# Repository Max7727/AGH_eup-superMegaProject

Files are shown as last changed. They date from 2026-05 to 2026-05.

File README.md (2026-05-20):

# AGH_eup-superMegaProject in Altium

### Schematics
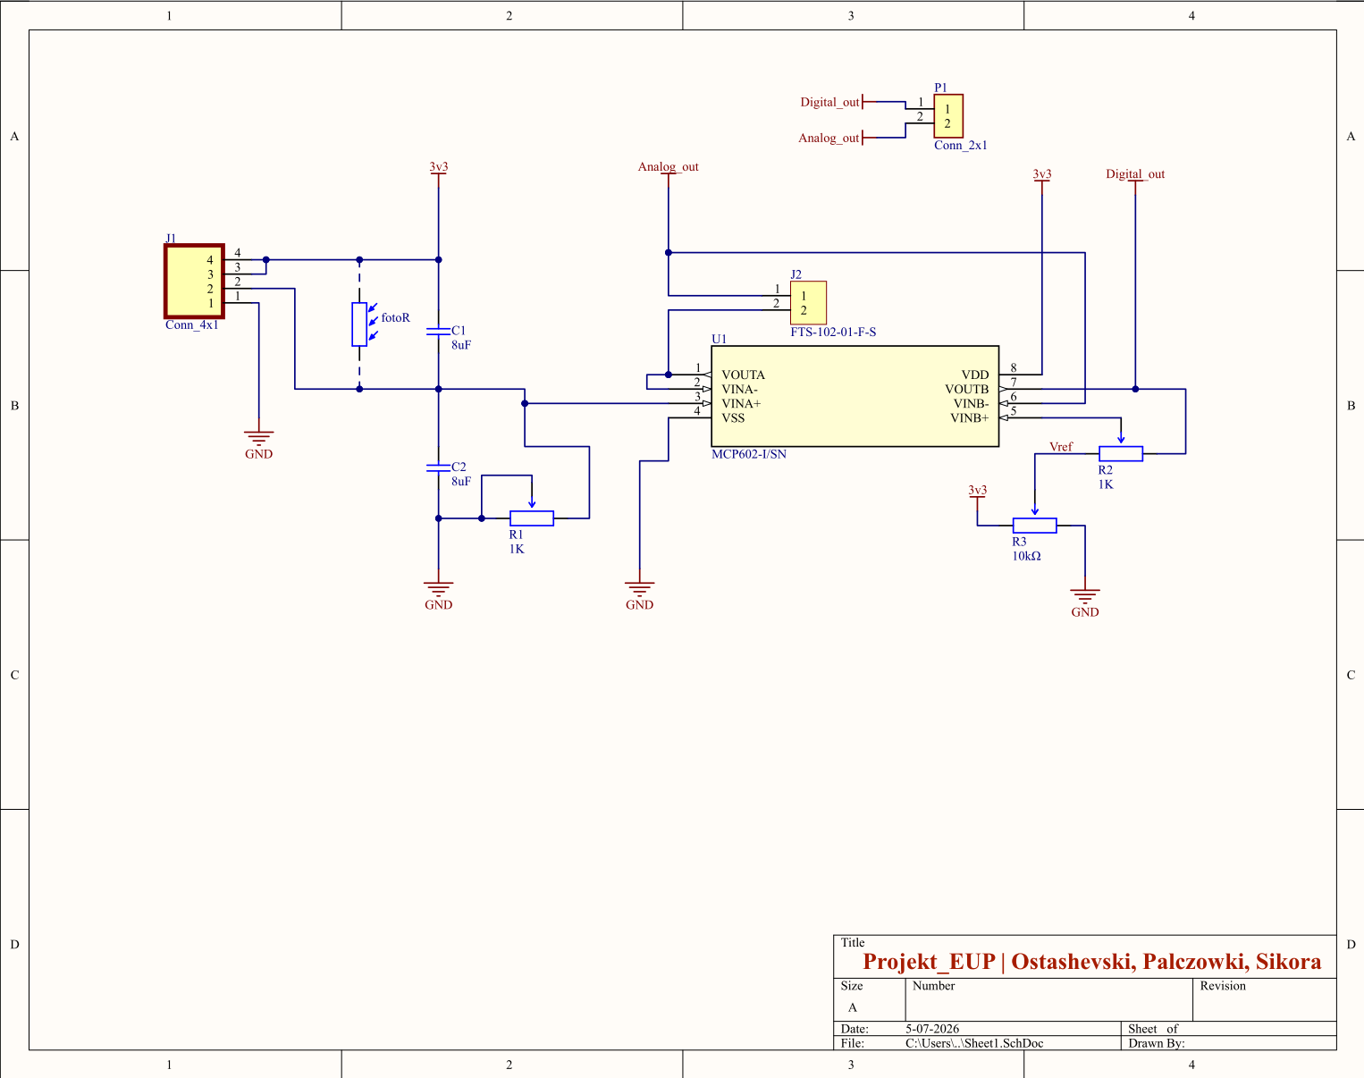
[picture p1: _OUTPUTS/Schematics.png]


### Prototype
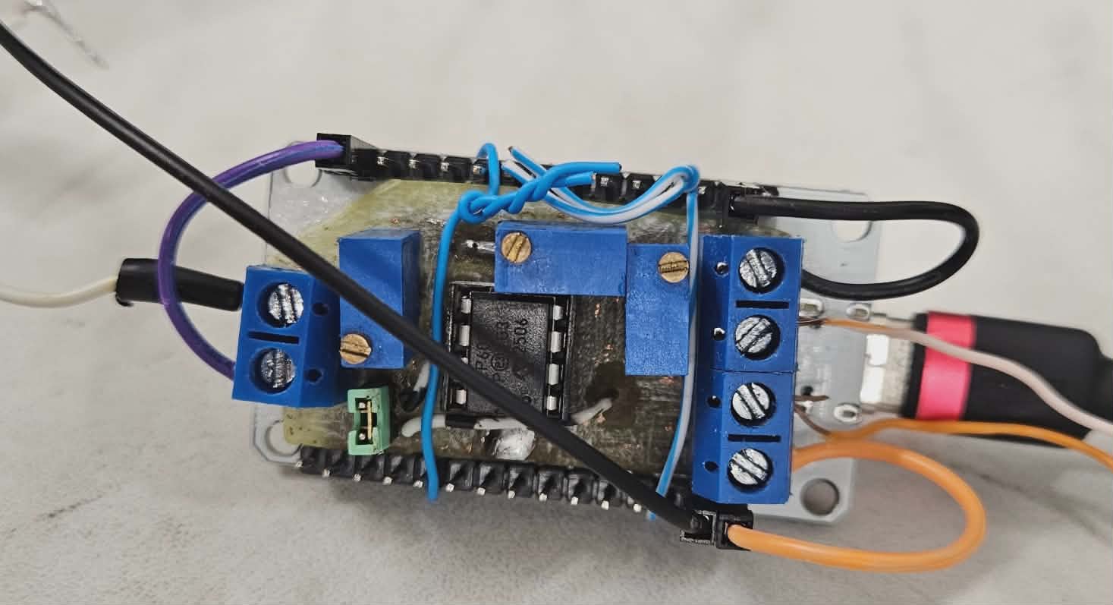
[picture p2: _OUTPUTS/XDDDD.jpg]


###  SuperMegaPCB_v1

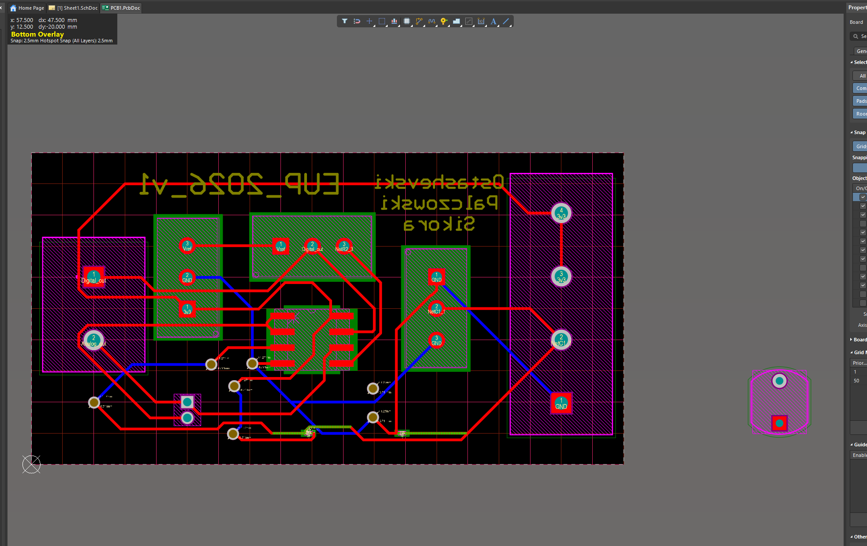
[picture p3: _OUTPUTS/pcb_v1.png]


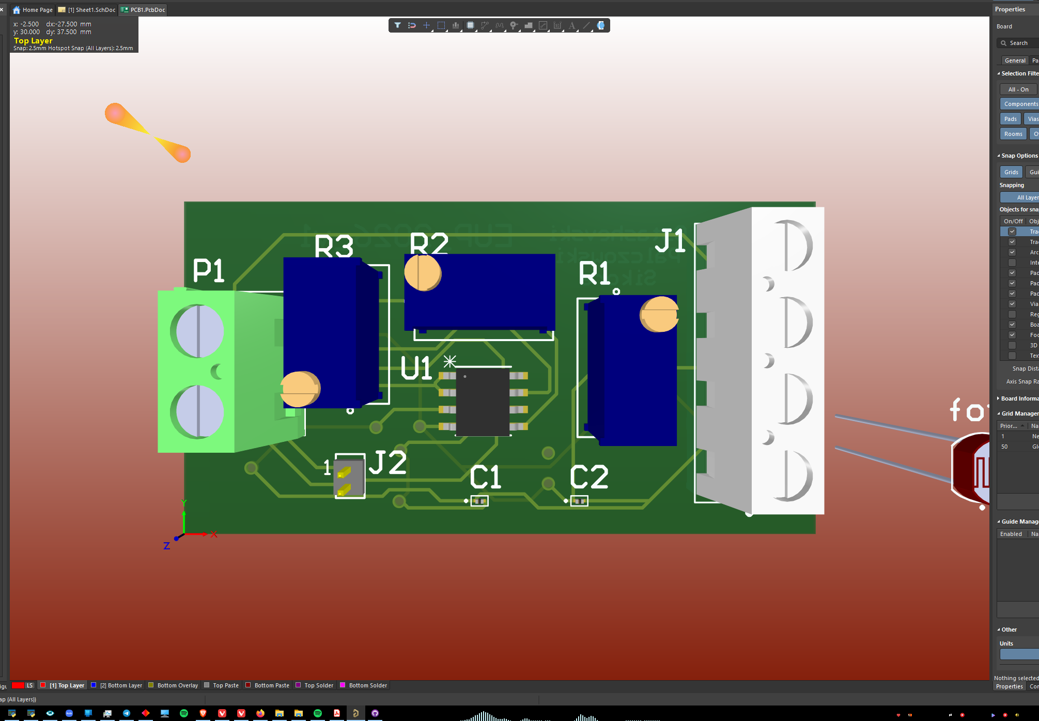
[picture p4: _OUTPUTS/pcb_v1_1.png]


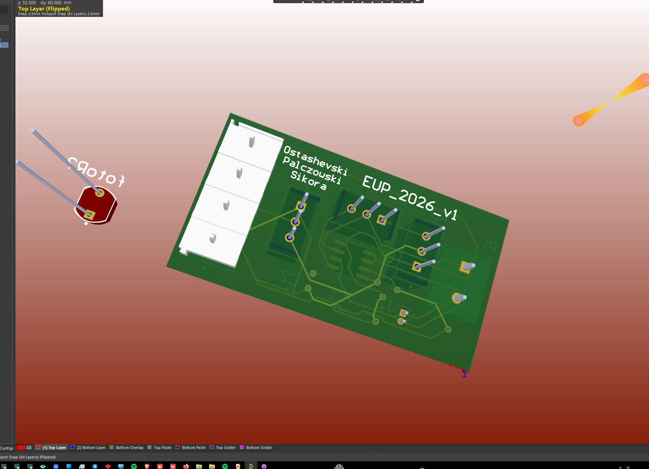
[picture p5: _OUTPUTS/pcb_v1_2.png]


###  SuperMegaPCB_v2
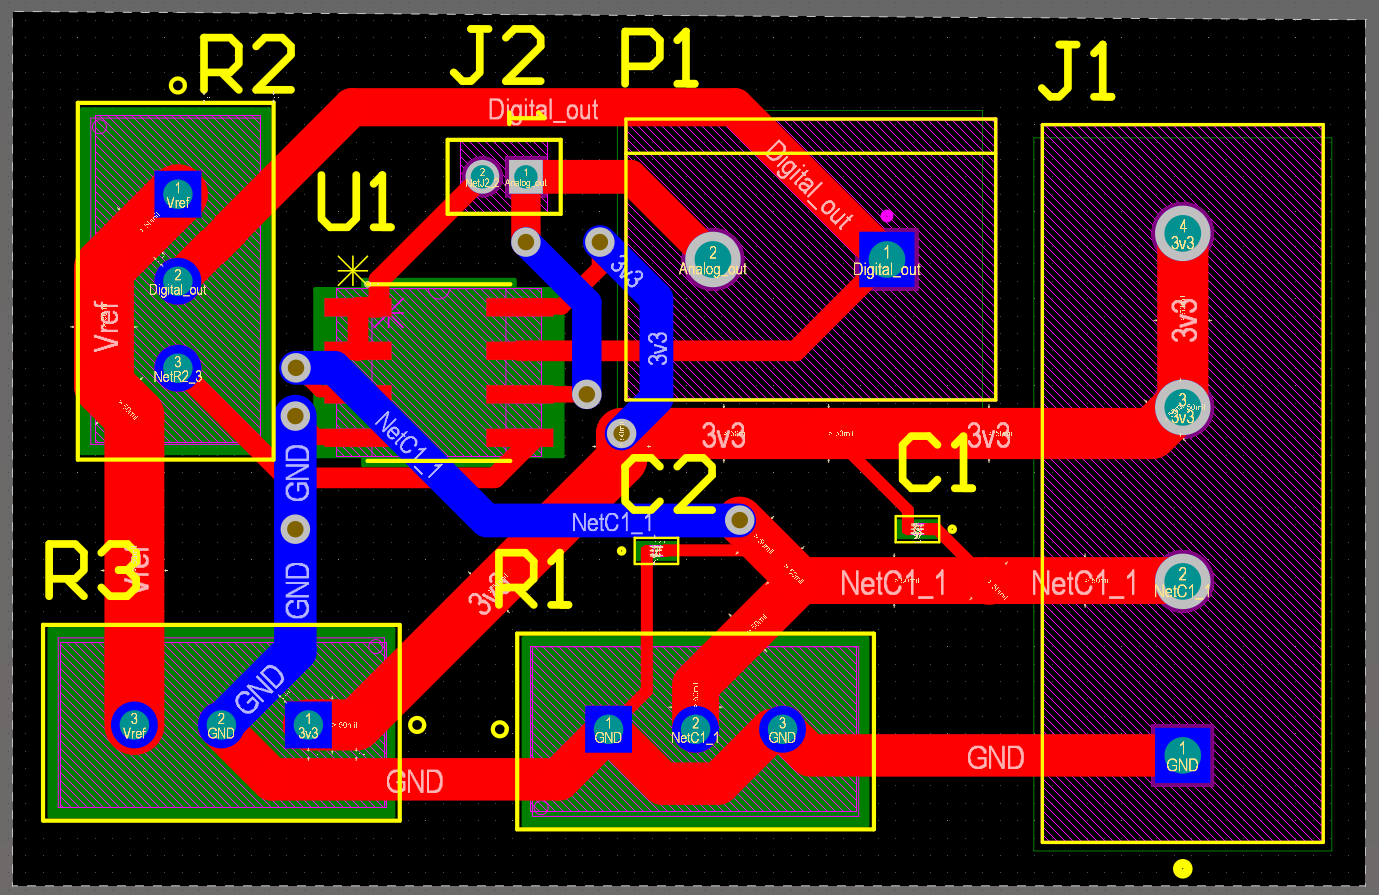
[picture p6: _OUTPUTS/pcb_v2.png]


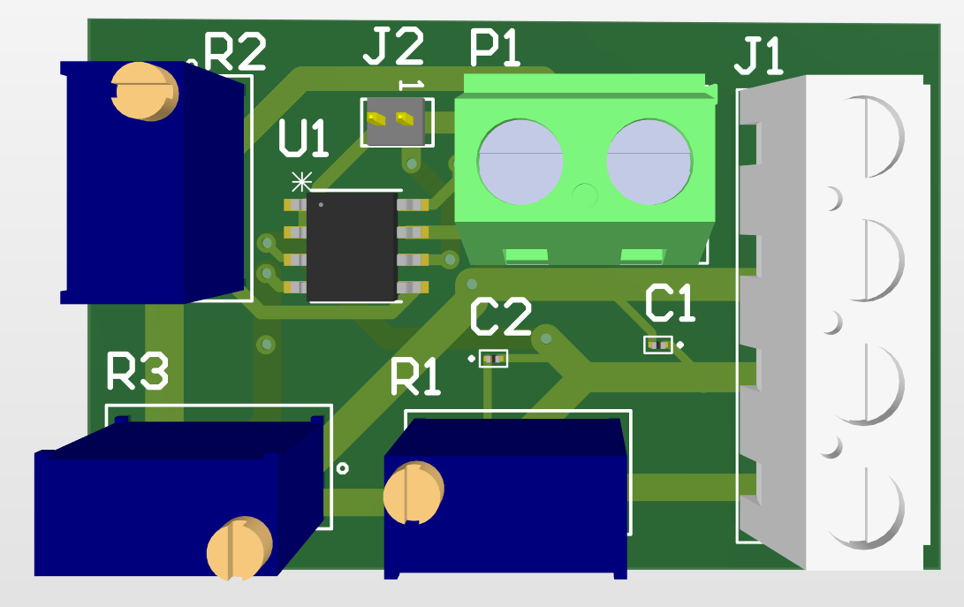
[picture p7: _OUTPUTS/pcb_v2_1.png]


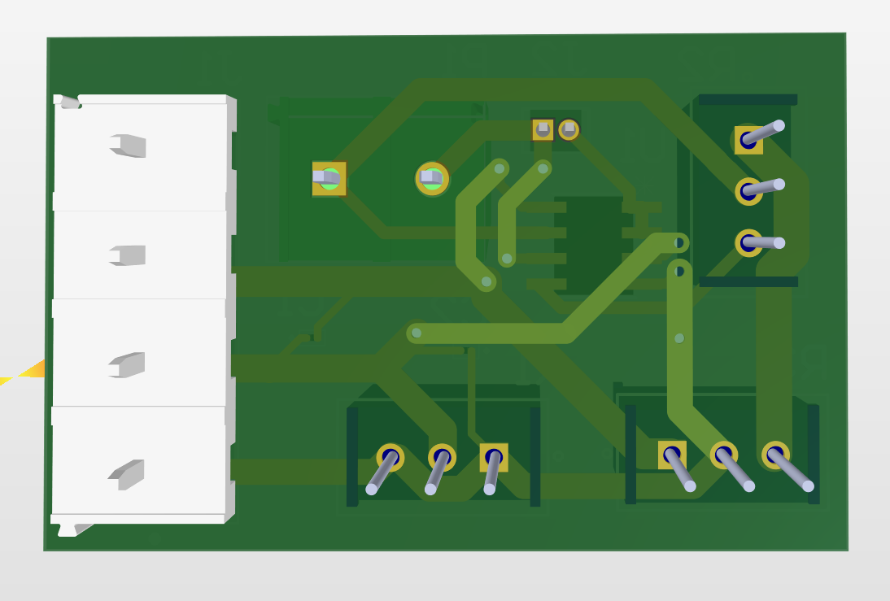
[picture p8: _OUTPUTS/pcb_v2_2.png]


### Special thanks to
Maksymilain Osyaszewski

Konrad Palczowski

Dawid Sikoea

### - - - 

Upload - 20May2026

Altium 25.8.1

:))))))

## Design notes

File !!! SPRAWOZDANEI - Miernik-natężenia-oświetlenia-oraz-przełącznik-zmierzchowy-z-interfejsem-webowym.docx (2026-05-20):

# Miernik natężenia oświetlenia oraz przełącznik zmierzchowy z interfejsem webowym (ESP32)

# 1. Wstęp

Projekt obejmował stworzenie hybrydowego (analogowo-cyfrowego) systemu monitorowania natężenia światła. Rozwiązanie łączy klasyczną elektronikę analogową (kondycjonowanie sygnału, sprzętowa histereza) z nowoczesnymi technologiami sieciowymi (ESP32, WebServer). Głównym celem było uzyskanie stabilnego pomiaru w luksach oraz realizacja przełącznika zmierzchowego.

# 2. Projekt układu analogowego i dobór elementów

### 2.1. Koncepcja wejścia: Dzielnik napięcia zamiast mostka

Początkowe założenia obejmowały wykorzystanie mostka Wheatstone'a. Po analizie zrezygnowaliśmy z tego rozwiązania. Nieliniowość mostka, nałożona na logarytmiczną i silnie nieliniową charakterystykę fotorezystorów, uniemożliwiłaby wyznaczenie prostego modelu matematycznego do obliczania luksów. Zastosowano dzielnik napięcia złożony z fotorezystora ( R_f ) oraz potencjometru wieloobrotowego.

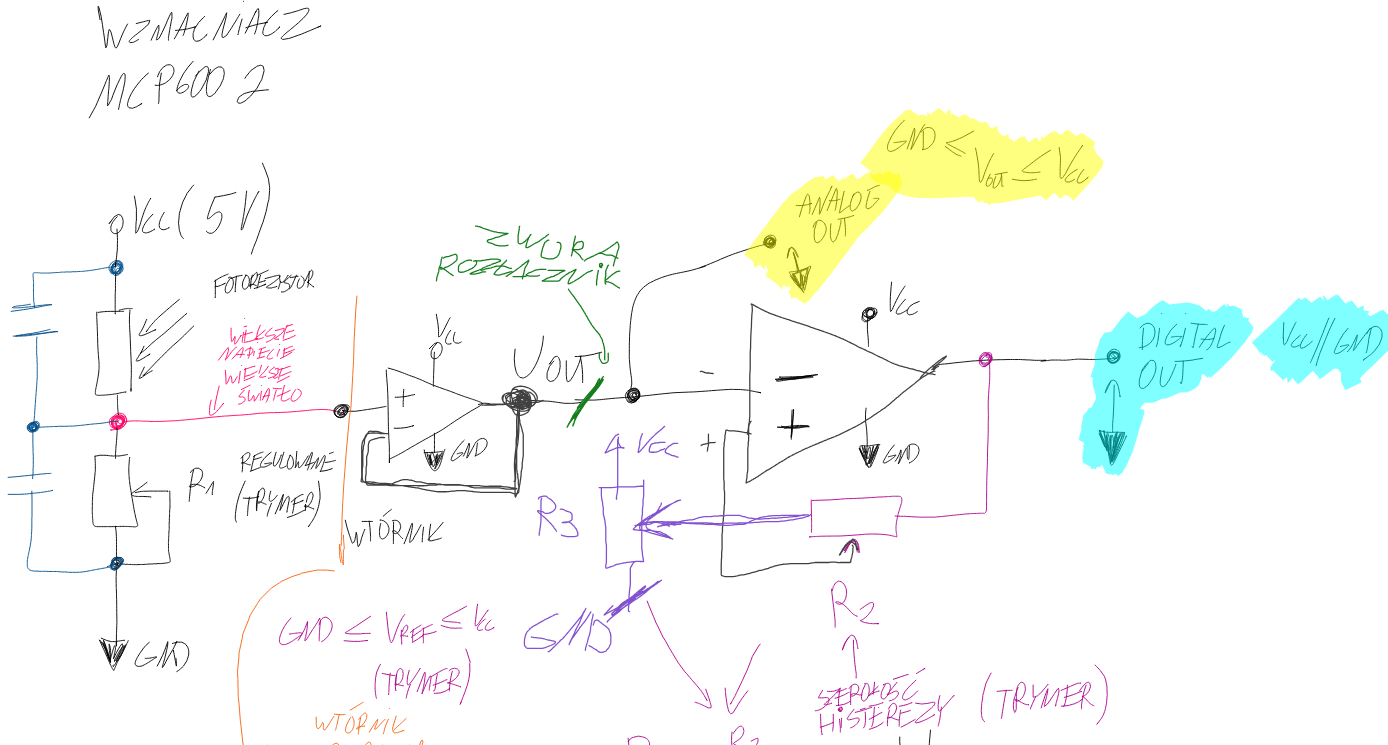
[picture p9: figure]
Brak opisu.

Rys. 1. Odręczny schemat ideowy układu przedstawiający koncepcję dzielnika, wtórnika i komparatora.

### 2.2. Dobór wzmacniacza operacyjnego

Ze względu na zasilanie układu napięciem 3.3V z modułu ESP32, zastosowanie standardowych wzmacniaczy (np. LM358) powodowałoby obcinanie sygnału wyjściowego. Zastosowano układ z wyjściem typu Rail-to-Rail (MCP602/MCP6002), co gwarantuje pełny zakres dynamiki sygnału.

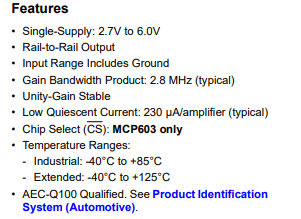
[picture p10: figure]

Rys. 2. Fragment noty katalogowej MCP6002 potwierdzający właściwości wyjścia Rail-to-Rail oraz zakres napięć roboczych.

### 2.3. Schemat ideowy

Sygnał z dzielnika podlega filtracji dolnoprzepustowej (kondensatory C_1 ,C_2 ) w celu eliminacji szumów, a następnie trafia na wtórnik napięciowy. Zapewnia to separację impedancyjną między czujnikiem a resztą układu.

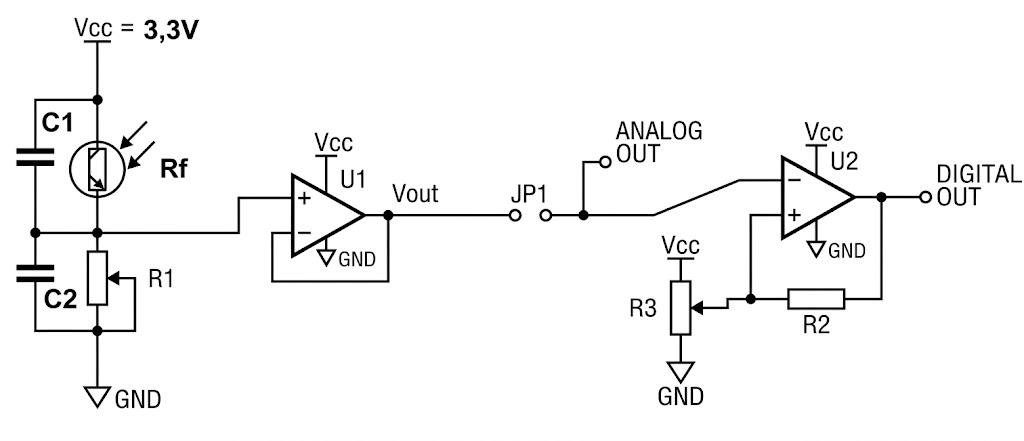
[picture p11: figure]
Brak opisu.

Rys. 3. Docelowy schemat układu analogowego wraz z podziałem na część pomiarową (wtórnik) i przełączającą (komparator).

# 3. Komparator i sprzętowa pętla histerezy

Druga część układu analogowego to komparator w konfiguracji odwracającej (spadek oświetlenia załącza wyjście). Aby zapobiec niestabilności i migotaniu sygnału na granicy przełączenia, zaimplementowano sprzętową histerezę poprzez dodatnie sprzężenie zwrotne.

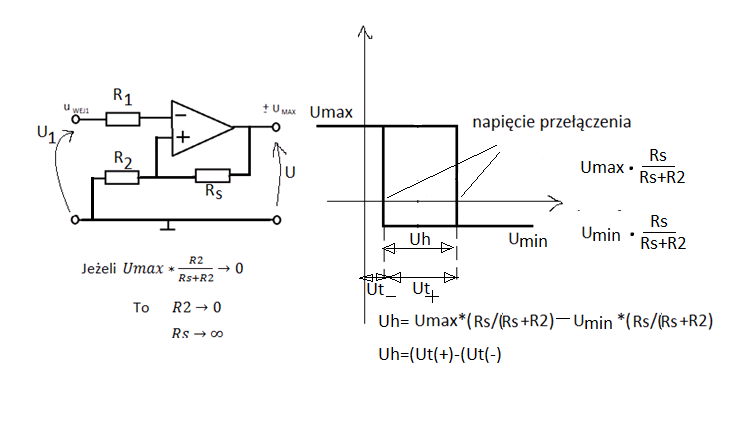
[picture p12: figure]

Rys. 4. Teoretyczny model pętli histerezy wraz z wyprowadzeniem wzorów na progi przełączania (U_max, U_min).

# 4. Symulacja komputerowa układu

Przed montażem fizycznym układ poddano symulacji w oprogramowaniu typu SPICE.

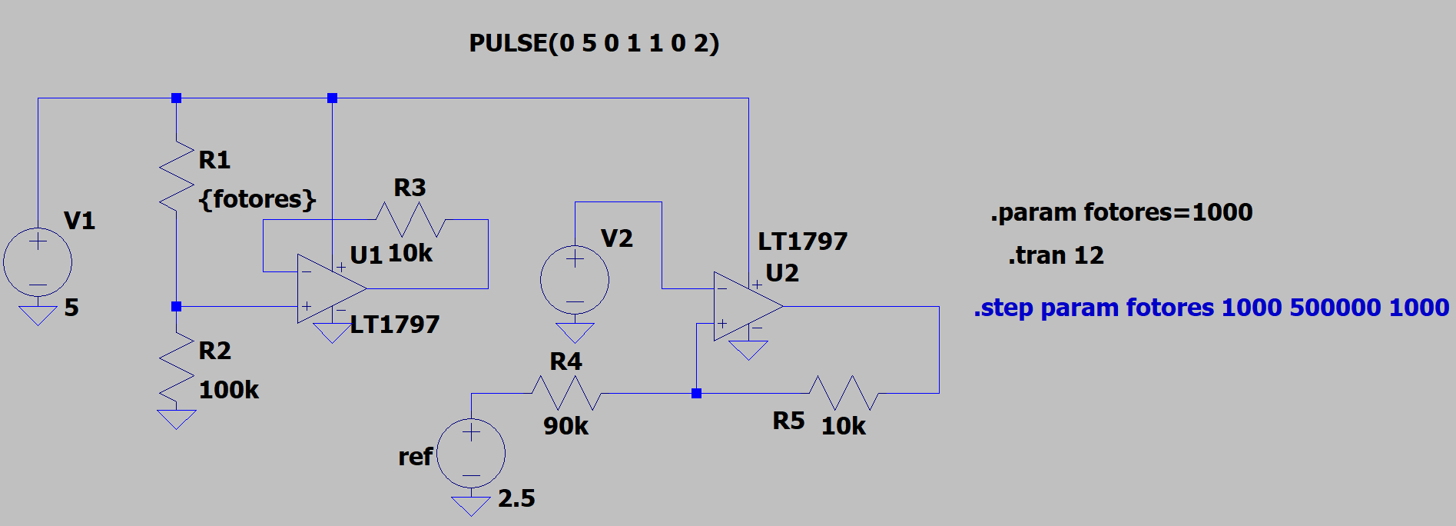
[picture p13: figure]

Rys.5. Model symulacyjny układu w programie LTspice

W celu zbadania pętli histerezy, na wejście układu podano sygnał trójkątny o amplitudzie od 0 do Vcc i niewysokiej częstotliwości. Zastosowanie takiego wymuszenia (sygnału trójkątnego lub sinusoidalnego) jest niezbędne - pozwala to przekraczać progi napięciowe w obu kierunkach i obserwować powstający na wyjściu sygnał prostokątny. Symulacja potwierdziła poprawne działanie sprzężenia zwrotnego - wyjście komparatora przełącza się w sposób zdecydowany, a na wykresie widoczne są dwa przesunięte względem siebie progi przełączania: górny (przy zaciemnianiu) i dolny (przy rozjaśnianiu). Dowodzi to, że sprzętowa histereza skutecznie zapobiegnie migotaniu układu w stanach przejściowych.

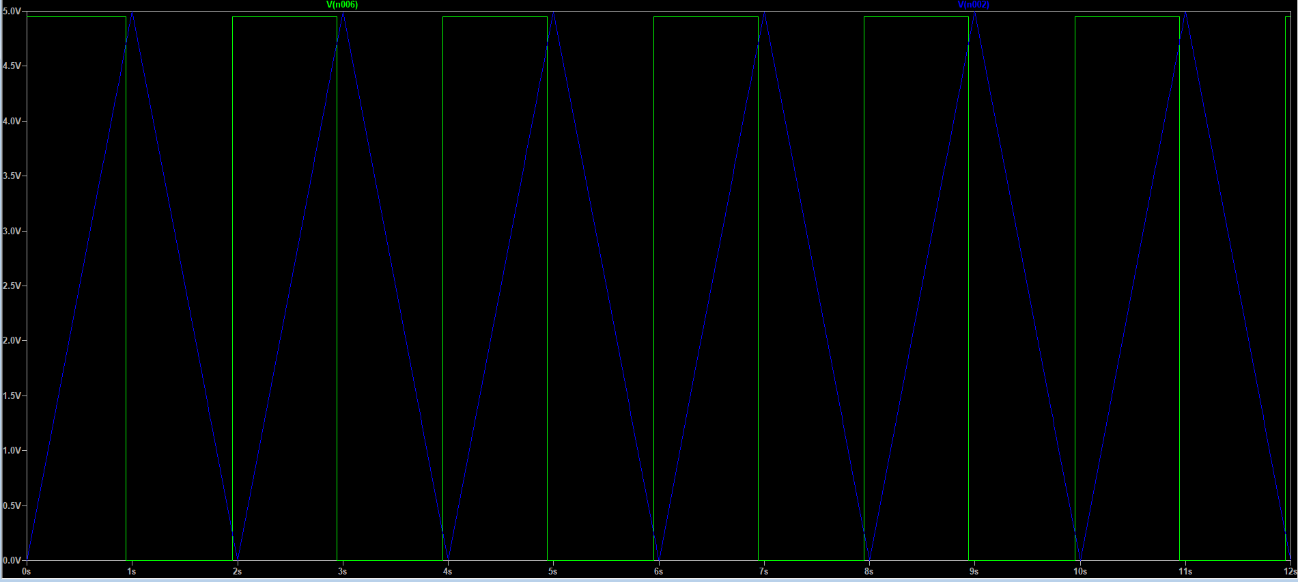
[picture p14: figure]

Rys. 6. Przebiegi czasowe z symulacji LTspice. Niebieski sygnał trójkątny imituje wolnozmienne napięcie wejściowe z dzielnika, natomiast zielony sygnał prostokątny to wyjście komparatora. Wyraźnie widać dwa różne progi napięciowe przełączania (górny przy narastaniu ok. 4.75V oraz dolny przy opadaniu ok. 0.25V), co bezpośrednio dowodzi poprawnego działania pętli histerezy.

# 5. Pomiary i badania dynamiki układu (Breadboard)

Wstępny montaż zrealizowano na płytce stykowej. Pozwoliło to na weryfikację dynamiki pracy fotorezystora oraz samego układu.

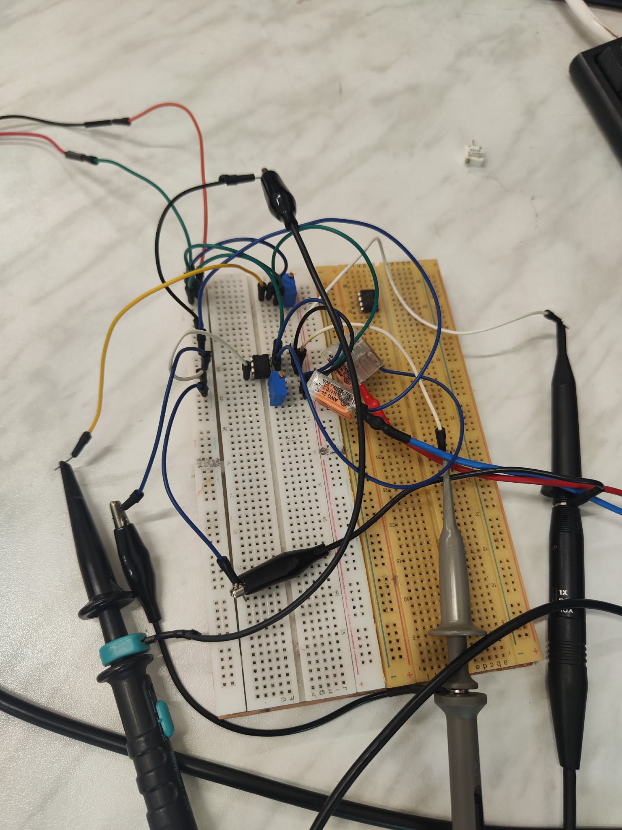
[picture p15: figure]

Rys 7. Prototyp na płytce stykowej, wykazujący problemy przez długość kabli

### 5.2. Pomiary pętli histerezy i problemy z oscylacjami

Zbadano zachowanie komparatora dla różnych nastaw histerezy. Zauważono, że długie odległości kabli na płytce stykowej wprowadzają pasożytnicze indukcyjności i pojemności. Powodowało to powstawanie szpilek, które można zaobserwować na zdjęciu poniżej.

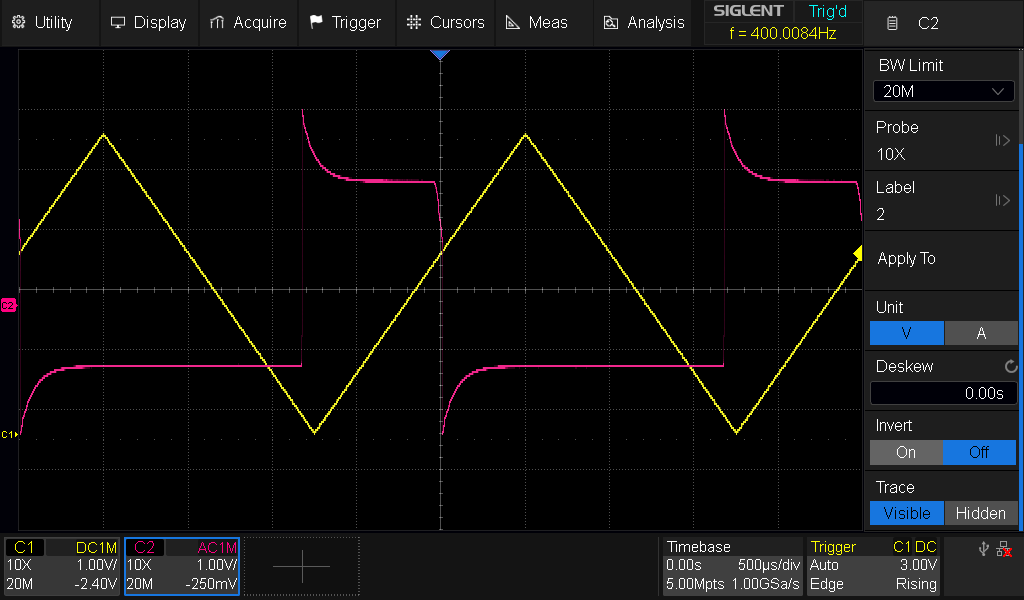
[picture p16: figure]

Rys. 8. Badanie punktów przełączania komparatora.

# 6. Projekt (Altium Designer), konstrukcja i montaż płytki PCB

Aby wyeliminować problemy z niestabilnością i oscylacjami, zaprojektowano i wykonano dedykowaną płytkę PCB.

Zanim przystąpiono do fizycznego wykonania układu, zaprojektowano obwód drukowany (PCB) w środowisku Altium Designer. Pozwoliło to na optymalne rozmieszczenie elementów, zminimalizowanie długości wrażliwych ścieżek analogowych oraz zachowanie odpowiednich odstępów izolacyjnych.

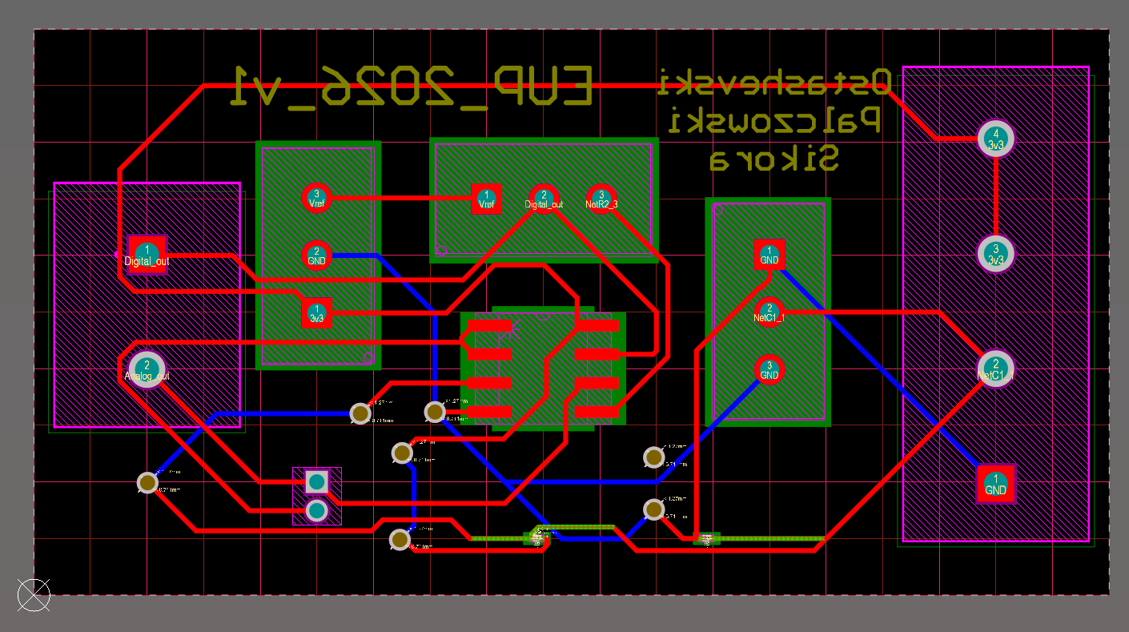
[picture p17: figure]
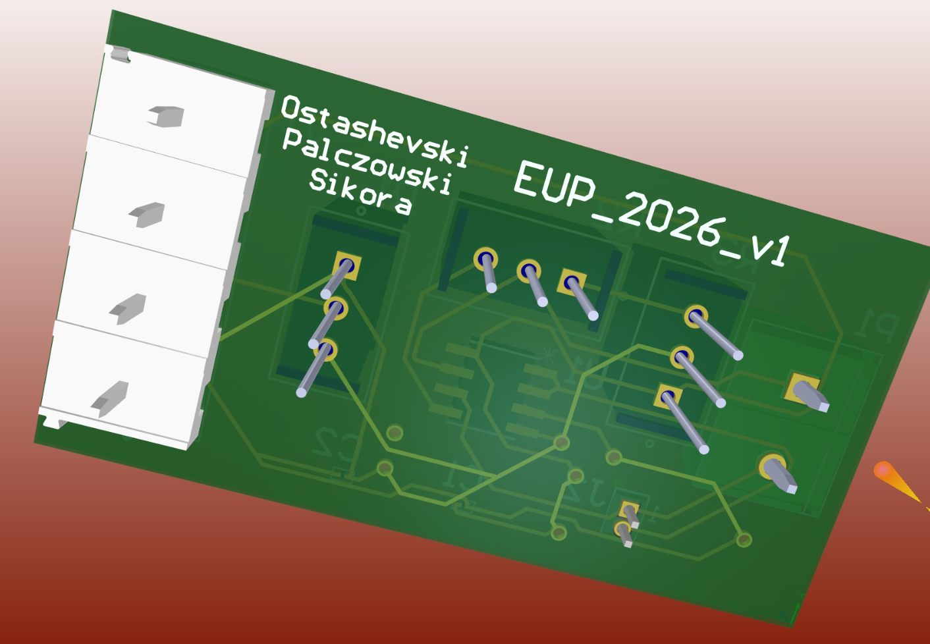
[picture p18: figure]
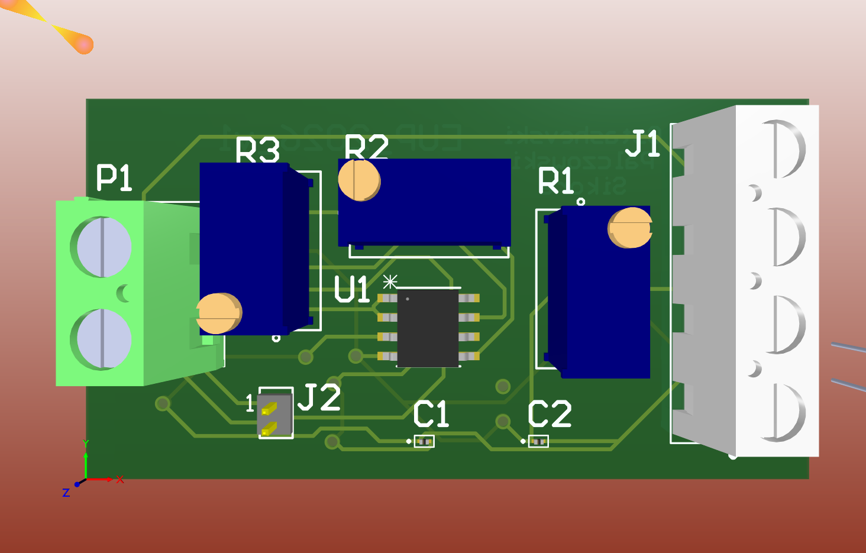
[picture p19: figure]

Rys. 9a, 9b, 9c. Projekt płytki drukowanej wykonany w środowisku Altium Designer.

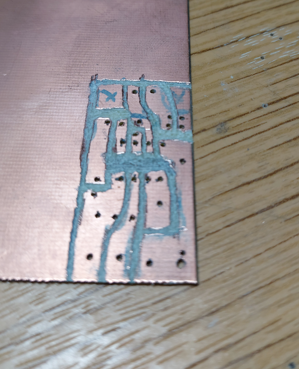
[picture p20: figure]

Rys. 10. Przygotowanie laminatu - mechaniczne trasowanie ścieżek i wiercenie otworów pod montaż

Proces obejmował zlutowanie elementów i pełne pokrycie miedzianych ścieżek cyną, co zmniejszyło ich rezystancję i zabezpieczyło przed utlenianiem powierzchniowym.

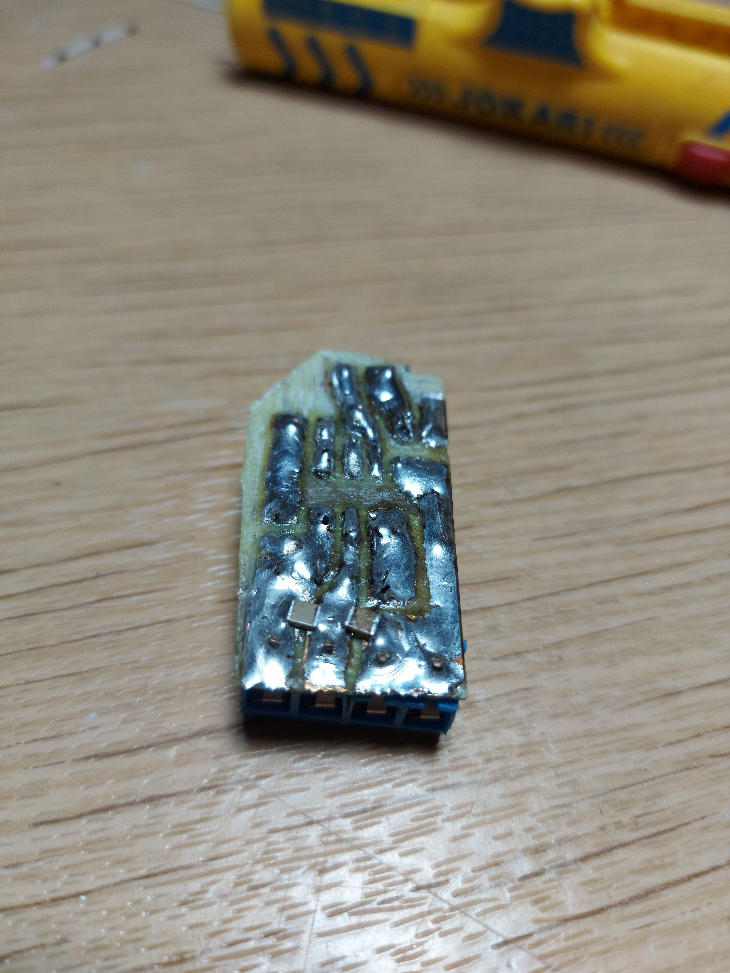
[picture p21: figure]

Rys. 11. Gotowy zmontowany moduł analogowy na płytce PCB (strona tylna)

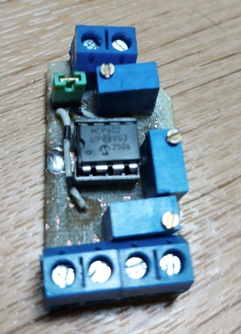
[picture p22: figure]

Rys. 12. Gotowy zmontowany moduł analogowy na płytce PCB (strona tylna)

# 7. Pomiary oscyloskopowe na gotowej PCB i badanie stałej czasowej

Dopiero zmontowanie układu na własnym laminacie pozwoliło na uzyskanie czystego, wolnego od oscylacji sygnału z wtórnika napięciowego. Na tym etapie podłączono układ do oscyloskopu w celu zbadania parametrów dynamicznych.
Dokonano serii pomiarów polegających na gwałtownym odkrywaniu i zakrywaniu źródła światła padającego na czujnik. Analiza przebiegów napięciowych na oscyloskopie pozwoliła precyzyjnie określić stałą czasową narastania i opadania sygnału.
Podczas badania okazało się że stała czasowa przy zakrywaniu (15.90ms) jest około 10 razy większa od stałej przy odkrywaniu czujnika (1.67ms).

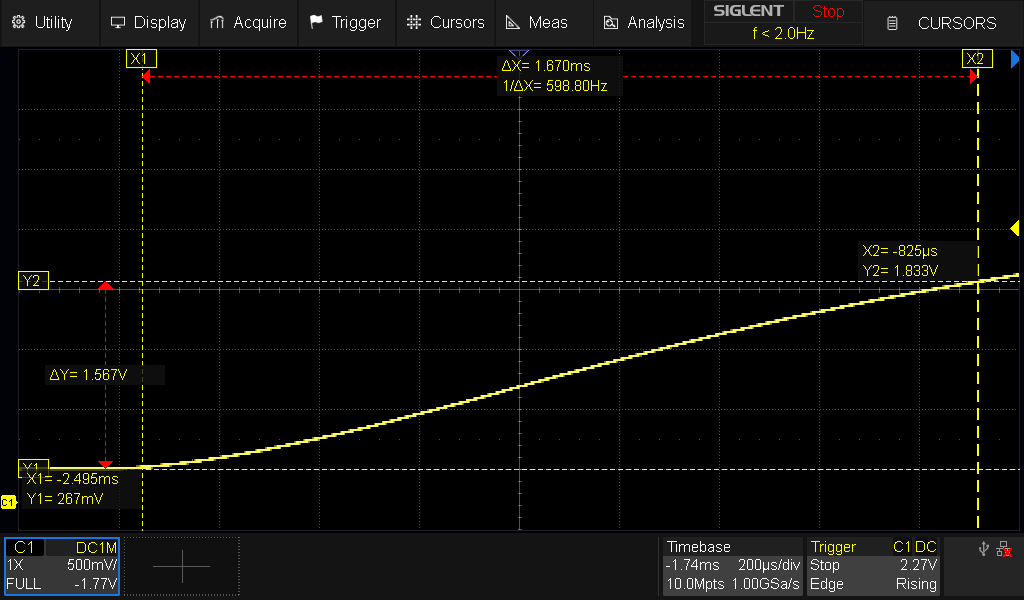
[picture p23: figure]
Brak opisu.

Rys. 13. Stała czasowa przy odkrywaniu czujnika

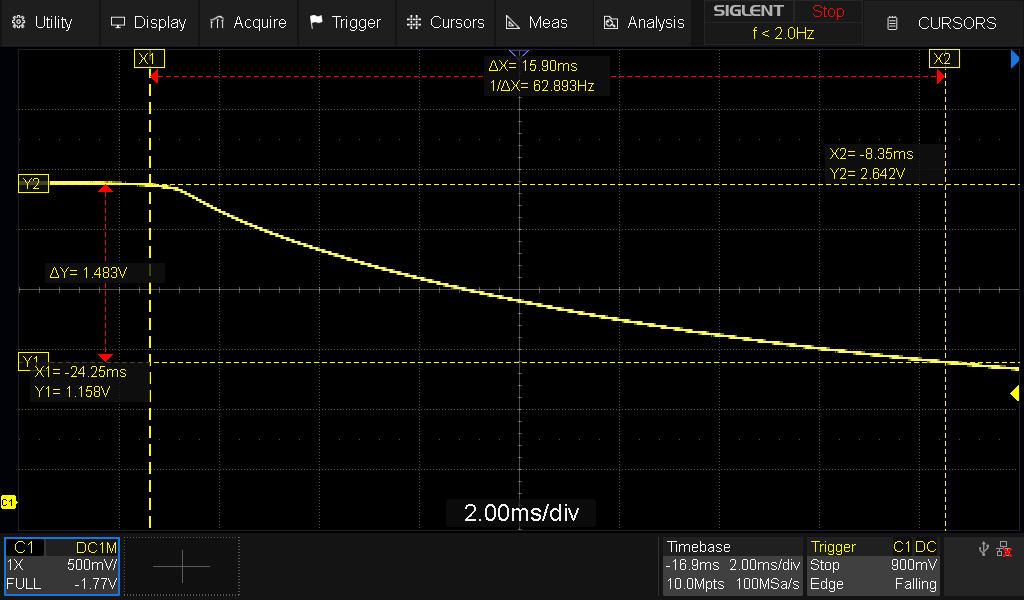
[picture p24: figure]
Brak opisu.

Rys. 14. Stała czasowa przy zakrywaniu czujnika

# 8. Przetwarzanie sygnału i integracja z ESP32

Z wyjścia wtórnika napięciowego wyprowadzono sygnał na wbudowany w ESP32 przetwornik ADC (12-bit). Skrypt w języku MicroPython wykonuje zbieranie próbek przez 200 ms w celu stabilizacji wyniku.

Następnie napięcie przeliczane jest na rezystancję fotorezystora R_f według wzoru:

R_f =R_(nastawne) ⋅((V_(zas))/(V_(adc))-1.0)

### 8.1 Kalibracja matematyczna czujnika

Wyznaczenie luksów na podstawie rezystancji wymagało zaawansowanej kalibracji wielopunktowej. Uwzględniono różne czynniki, takie jak widmo źródła światła, jego kolor oraz migotanie. Do przeprowadzenia dokładnych testów wykorzystano naświetlacz LED ze sterownikiem stałoprądowym (CC driver). Metodyka pomiarowa polegała na zmianie prądu zasilającego diody naświetlacza, a także modyfikowaniu odległości i kąta rozproszenia światła padającego na układ.

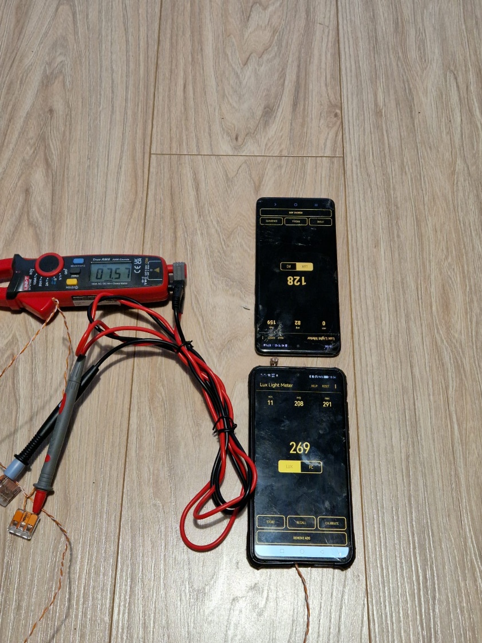
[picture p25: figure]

Rys. 15. Kalibracja wykorzystująca smartfony Samsung A71 oraz Huawei Mate 20 jako mierniki referencyjne.

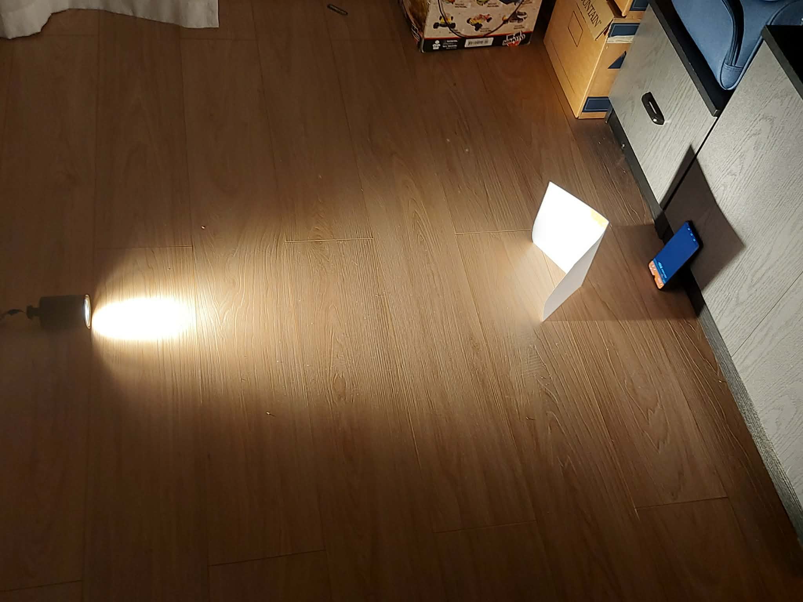
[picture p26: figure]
Brak opisu.

Rys. 16. Stanowisko pomiarowe

Dla poszczególnych warunków oświetleniowych, odczytywano i zapisywano w tabeli pary danych: rezystancję fotorezystora mierzoną bezpośrednio przy użyciu omomierza oraz odpowiadające jej natężenie światła w luksach, wskazywane przez dwa smartfony referencyjne (Samsung A71 oraz Huawei Mate 20).

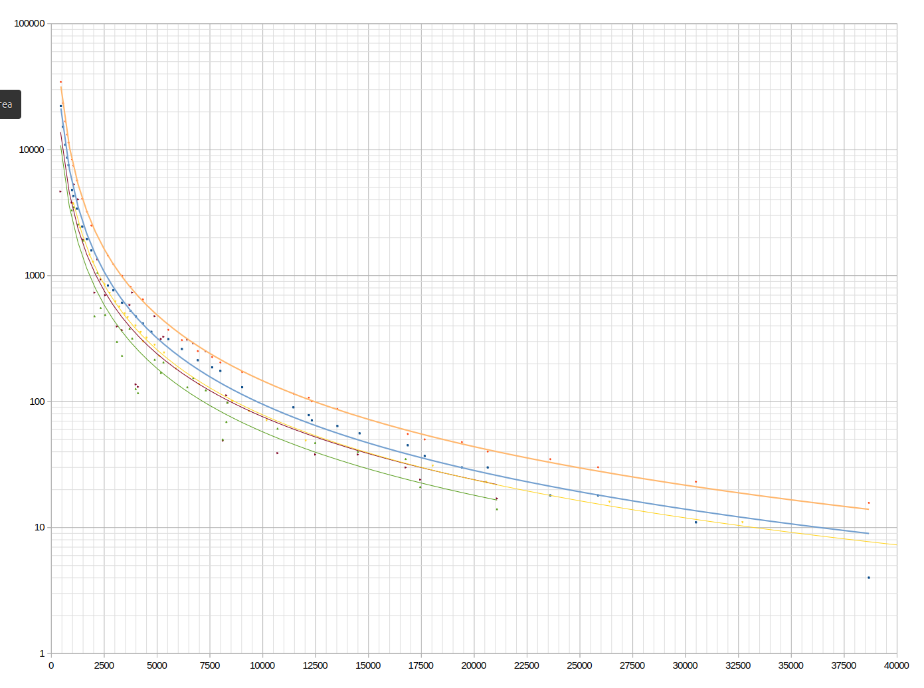
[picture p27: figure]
Brak opisu.

Rys. 17. Wyniki kalibracji zarejestrowane w programie Excel

Dopiero po zebraniu tabeli par wyników empirycznych (rezystancja vs luksy dla różnych źródeł i odległości), przystąpiono do dopasowania matematycznego. Na podstawie zebranych danych wygenerowano modele regresji potęgowej. Wykorzystano dwie niezależne krzywe dla każdego z urządzeń referencyjnych:

- Lux_(A71) =910521918.79⋅R^(-1.745)
- Lux_(Mate20) =1291610194.03⋅R^(-1.736)

### 8.2 Interfejs użytkownika (Web Server)

ESP32 połączony z siecią Wi-Fi pełni rolę serwera WWW. Aplikacja frontendowa, napisana w HTML i CSS, wykorzystuje JavaScript do cyklicznego odpytywania mikrokontrolera o nowe dane.

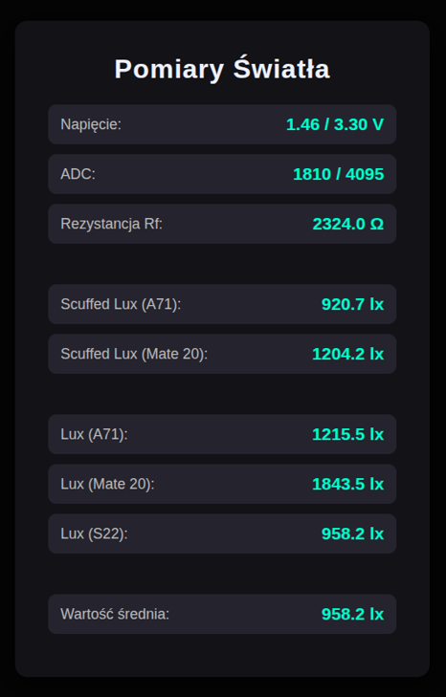
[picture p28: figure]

Rys. 18. Interfejs użytkownika w przeglądarce internetowej

# 9. Podsumowanie i wnioski

Praktyka vs Teoria: Projekt zweryfikował wady płytek stykowych (Breadboard). Długie przewody łączeniowe wprowadzały pasożytnicze indukcyjności i pojemności, co skutkowało wybudzaniem się oscylacji. Wykonanie dedykowanego PCB z grubymi, ocynowanymi ścieżkami całkowicie ustabilizowało tor analogowy.

Asymetria parametrów dynamicznych czujnika: Analiza przebiegów oscyloskopowych na zmontowanej płytce PCB ujawniła specyficzną właściwość fizyczną fotorezystora. Układ reaguje znacznie wolniej na spadek oświetlenia - stała czasowa przy zakrywaniu czujnika wynosi 15.90 ms, co jest wartością niemal 10-krotnie większą niż w przypadku jego nagłego naświetlenia (1.67 ms).

Kluczowość układów Rail-to-Rail: Przy systemach wbudowanych o napięciu 3.3V dobór odpowiednich wzmacniaczy jest krytyczny do wykorzystania pełnej rozdzielczości przetworników ADC.

Złożoność sensorów optycznych: Fotorezystory nie są elementami liniowymi. Osiągnięcie względnie dokładnego wyniku w luksach wiązało się ze żmudną kalibracją i koniecznością zastosowania regresji potęgowej z wykładnikami rzędu -1.74 .

Przewaga architektury hybrydowej: Zbudowanie systemu integrującego klasyczną elektronikę analogową (kondycjonowanie sygnału, separacja impedancyjna) z mikrokontrolerem ESP32 okazało się rozwiązaniem wysoce efektywnym. Część analogowa zapewnia sprzętową stabilność, podczas gdy mikrokontroler z powodzeniem przejmuje na siebie ciężar uśredniania próbek , przeliczania skomplikowanych modeli kalibracyjnych oraz udostępniania danych w sieci poprzez wbudowany serwer WWW.

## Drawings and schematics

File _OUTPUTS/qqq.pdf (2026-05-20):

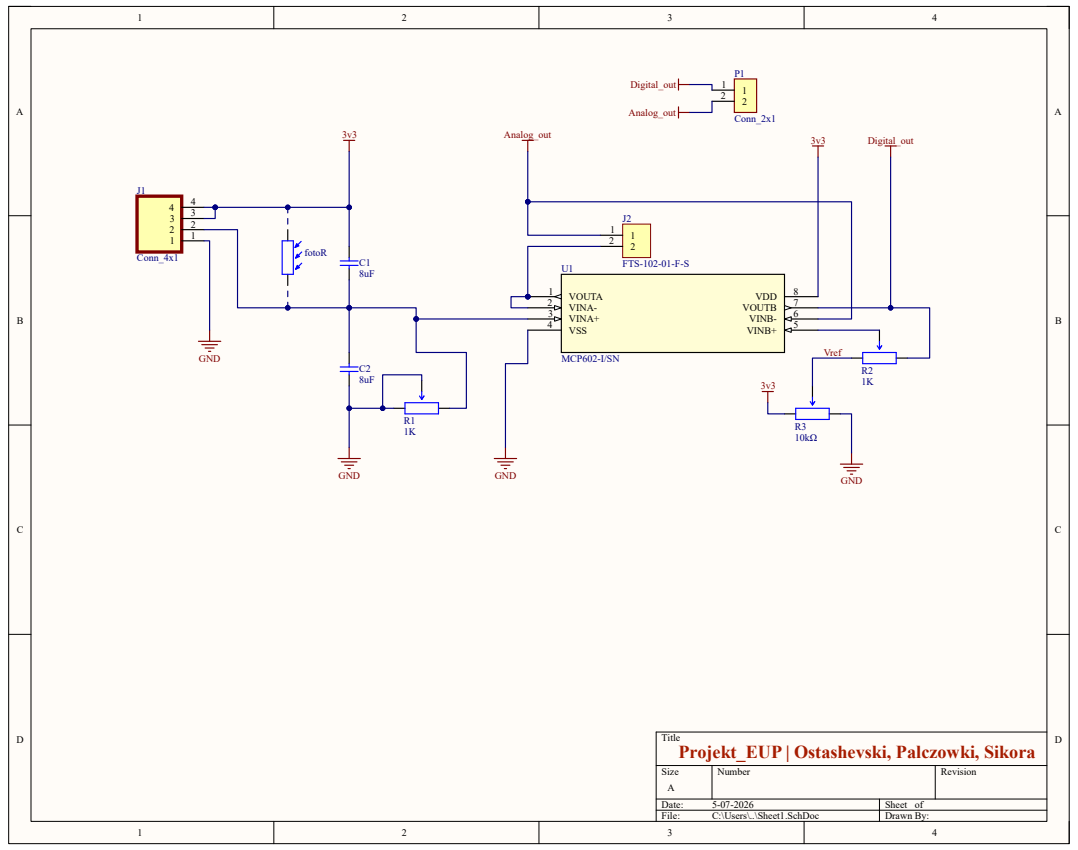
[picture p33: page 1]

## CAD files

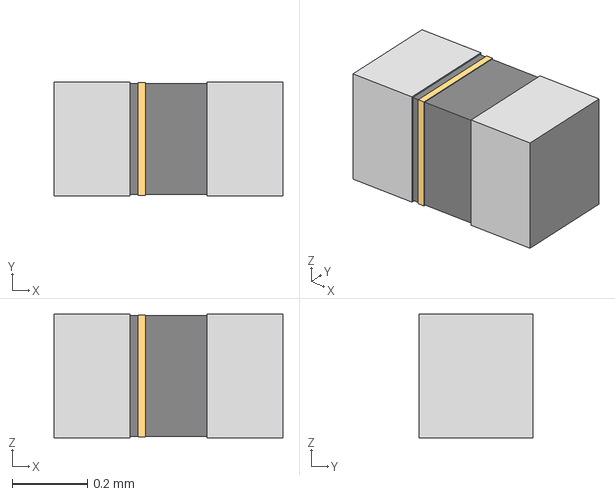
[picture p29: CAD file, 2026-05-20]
Capacitor/Altium/G-033_MUR.step
0.61 x 0.304 x 0.33 mm

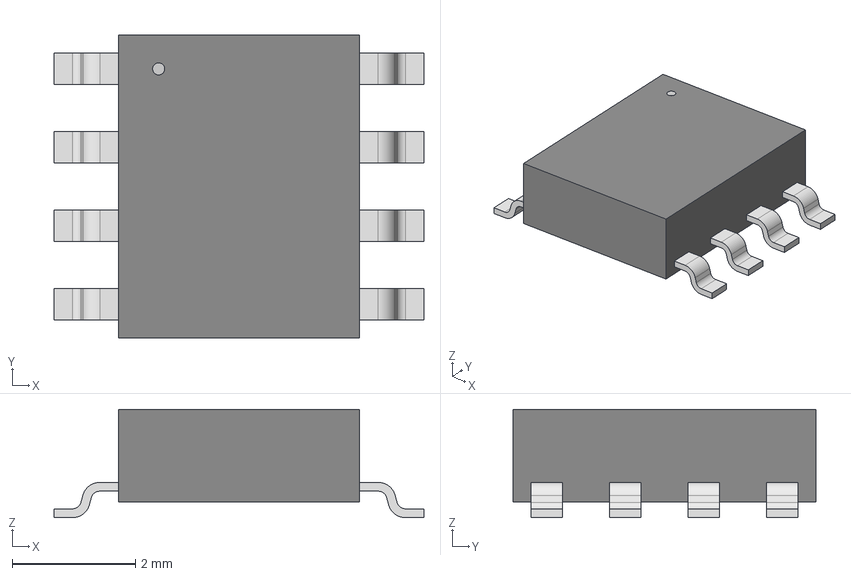
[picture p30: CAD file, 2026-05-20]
OpAmpUpYoAss/MCP602-I-SN/SOIC8-N_MC_MCH.step
5.99 x 4.90 x 1.75 mm

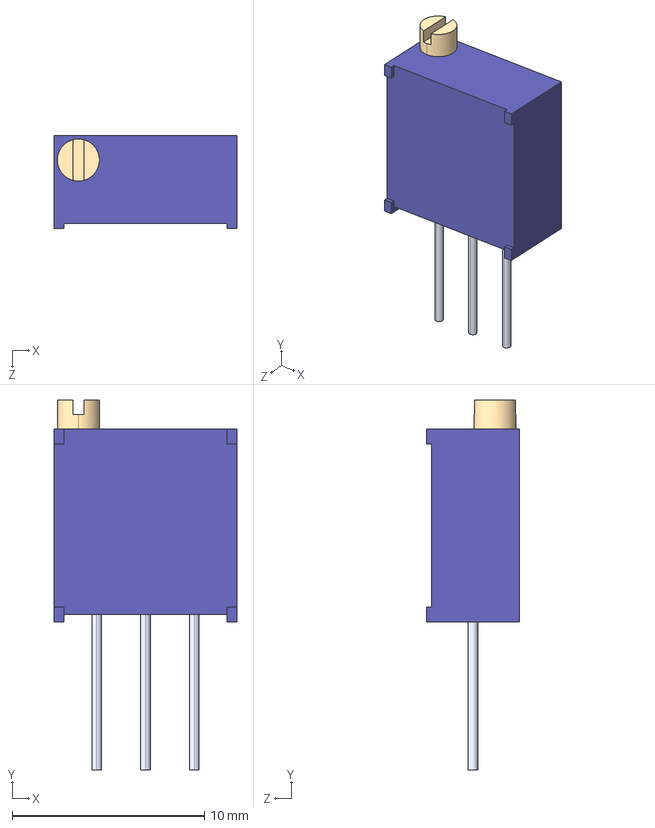
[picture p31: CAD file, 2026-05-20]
R_nastawny/PV36W104C01B00.STEP
9.53 x 19.3 x 4.83 mm

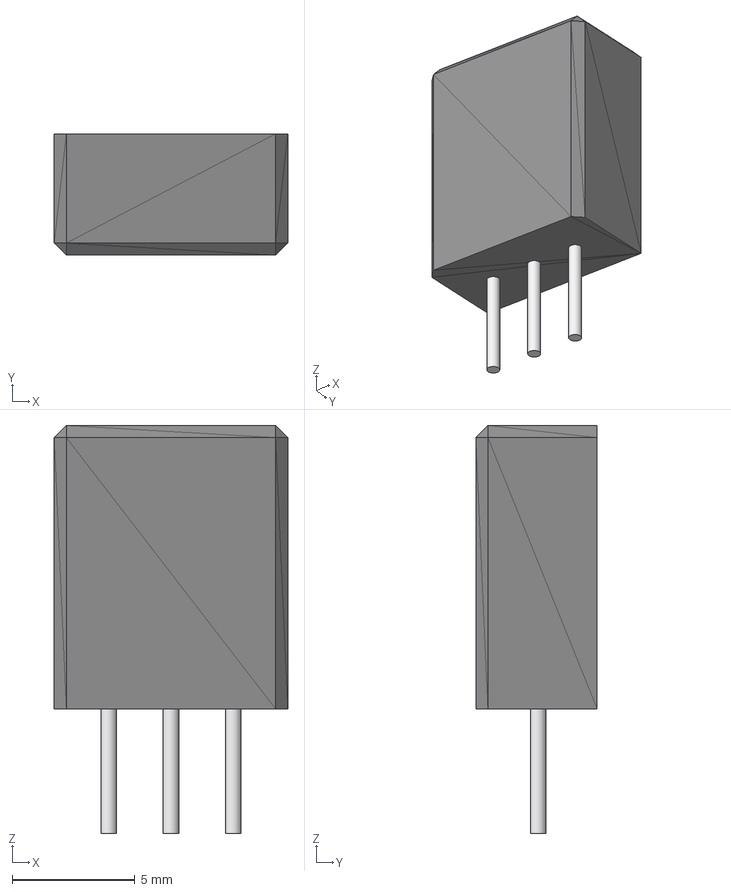
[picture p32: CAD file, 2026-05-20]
R_nastawny/PV36W104C01B00/POT_PV36W_BRN.step
9.52 x 4.95 x 16.6 mm

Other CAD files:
Capacitor/G-033_MUR.step
OpAmpUpYoAss/SOIC8-N_MC_MCH.step
